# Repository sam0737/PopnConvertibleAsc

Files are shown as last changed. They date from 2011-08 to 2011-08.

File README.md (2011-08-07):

Pop'n Convertible ASC (Arcade Style Controller)
==============================================
中文版README請往下看。

[Pop'n Music][popnwiki] is a music simulation game produced by KONAMI.

This project is about making an arcade like, portable controller for the Pop'n Music game. The controller is designed to be connected to PC through USB. The buon push emulates keyboard key hits. (How to obtain the game to run on PC is out of topic)

Visit the [album][] to see some action shots.

Contents
--------
The files here are contains all of the design - hardware and software.

 * Mechanical Design
   A convertible stand design for holding the big buttons, designed to be made from acrylic (Plexiglas) and laser cut. This contains all the design source file and output.
 * Firmware
   Source code of the AVR Firmware to be loaded into any [LUFA][] supported device, to translate button pushes into keyboard keystrokes. It is a Keyboard HID and requires no driver for most OS.

Firmware Hardware
-----------------
The firmware is to translate button pushes as USB keyboard key press for PC. If you want to hook this up to Playstation, you don't need this firmware. You should deassemble a PS controller and hook it up instead.

The firmware can be compile for any [LUFA][] supported dev board, such as [minimus][]. Please refer to the LUFA website for supported models. Dev boards are usually sold at around 10 to 20 USD.

It is to be compiled with GCC + avr-libc. [WinAVR][] is such a toolchain for Windows. Upon connect, it requires no driver operate as it works as a keyboard device. 

Electronics
-----------
The buttons are to Port B pin 0 to pin 7, and Port C pin 7 from left to right.

 * On the microswitch: connect the Normal Open lead to the MCU, common lead to the GND.
 * On the button LED: connect positive lead to Vcc, negative lead to Normal Open of the microswitch. This assume the LED component has a built-in resistor inside (Those I bought does include a 300-ohm connected in series). The Vcc could be powered by 9V to 12V, as well as from the USB 5V directly except that it might not be bright enough.

Each button push would generate a key press signal of 1 to 9 accordingly.

Action shot
-----------
See [album]

Building Cost
-------------
Acrylic parts material + laser cutting: 30 USD
Minimus USB dev board: 10 USD
Buttons (LED + Microswitch included): 25 USD
Being able to play Pop'n Music with authentic controller: Priceless

Wires, soldering tools, etc. are not included.

Pop'n 可分拆式街機控制盤
========================
[Pop'n Music][popnwiki]是一套由KONAMI發行的音樂模擬遊戲。

這個專案是關於制作一個可與街機大小相比，但相對方便收納的控制器。控制器是以USB方式與電腦連接，按鍵會模擬成鍵盤按鈕一樣。(至於怎樣取得PC上運行的Pop'n Music版本則是題外話)

成品照片請看[相冊][album]。

內容
----
這裏提供了整件成品的所有文檔 - 硬件和軟件。

 * Mechanical Design - 硬件機械設計
   一個可分拆的腳架，當然是用來固定按鈕用的。設計上是以亞克力 (又名亞加力、有機玻璃)為材，以激光切割製成。這有了所有的設計原文件和輸出圖檔。
 * Firmware
   AVR固件的原代碼，適用於所有支持[LUFA][]架構的AVR開發版，用以將按鍵訊號轉成USB鍵盤訊號給電腦。電腦將會把它看成一般鍵盤硬件一樣，無需安裝任何驅動即可使用。

固件所用之硬件
--------------
這裏的固件是用來把按鍵訊號轉成USB鍵盤訊號給電腦。如果你要將這些按鈕接到Playstation的話，你不需要固件，也不需要AVR開發版，取而代之是你要肢解一個Playstation手掣並把線接上去。

本固件適用於所有支持[LUFA]的AVR硬件，例如[minimus]。有關硬件支持請參考LUFA的網頁。一般來說價格在於10到20美元之間。

本固件需要用GCC和avr-libc編譯才可使用。Windows用家可考慮使用[WivAVR][]來解決。硬件連上USB後，由於會模擬成鍵盤，所以電腦不需要配備任何驅動。

電子
----
那9個鍵由左至右應接到AVR B0到B7以及C7腳。

 * 微動開關方面: 常開(Normal Open - NO)接到AVR的腳。COM接地 (GND)。
 * LED方面:正極接Vcc，負極接到微動的常開腳。這假設你的LED模組中包含一個相應的電阻。(我買的有一個300歐電阻串連著) Vcc可以是其他9V-12V電源，USB的也行不過有點暗。

每按下按鈕就等同按了鍵盤的1-9一樣。

成品
----
看[圖][album]

製作成本
--------
亞克力材料及激光切割手工: 180人民幣
Minimus USB dev board: 60人民幣
特大按鈕，連微動和LED: 170人民幣
在家尤如在機舖中玩Pop'n: 此刻無賈

電線、焊接工具等不計算在內。

[popnwiki]: http://en.wikipedia.org/wiki/Pop'n_Music
[album]: https://picasaweb.google.com/103994691685219285374/PopnConvertibleAsc
[LUFA]: http://www.fourwalledcubicle.com/LUFA.php "Lightweight USB Framework for AVRs"
[minimus]: http://minimususb.com/
[WinAvr]: http://winavr.sourceforge.net/

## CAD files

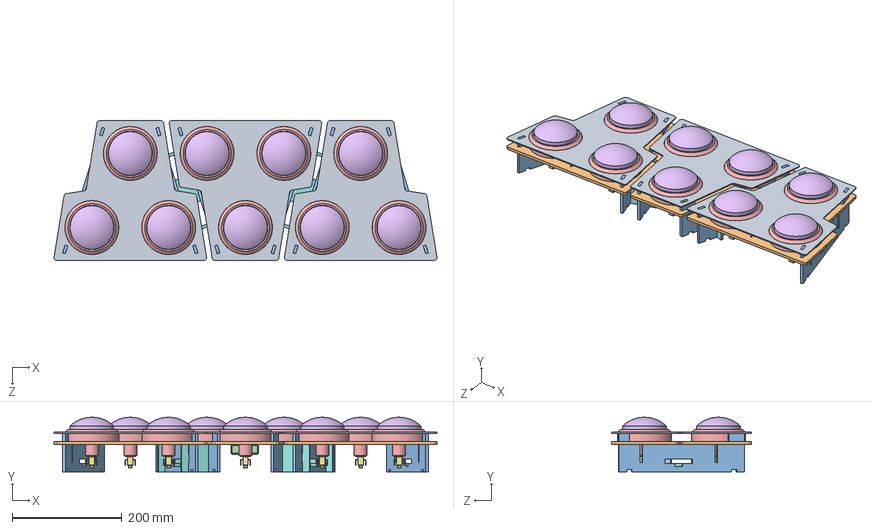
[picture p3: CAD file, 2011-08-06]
Mechnical Design/Assembly.SLDASM
698.2 x 99.6 x 255.0 mm
Top Plate x 3
Middle Plate x 3
Support x 6
Electronics
Button Shield x 9
Button Dome x 9
Microswitch x 9
Vertical Interlock x 6

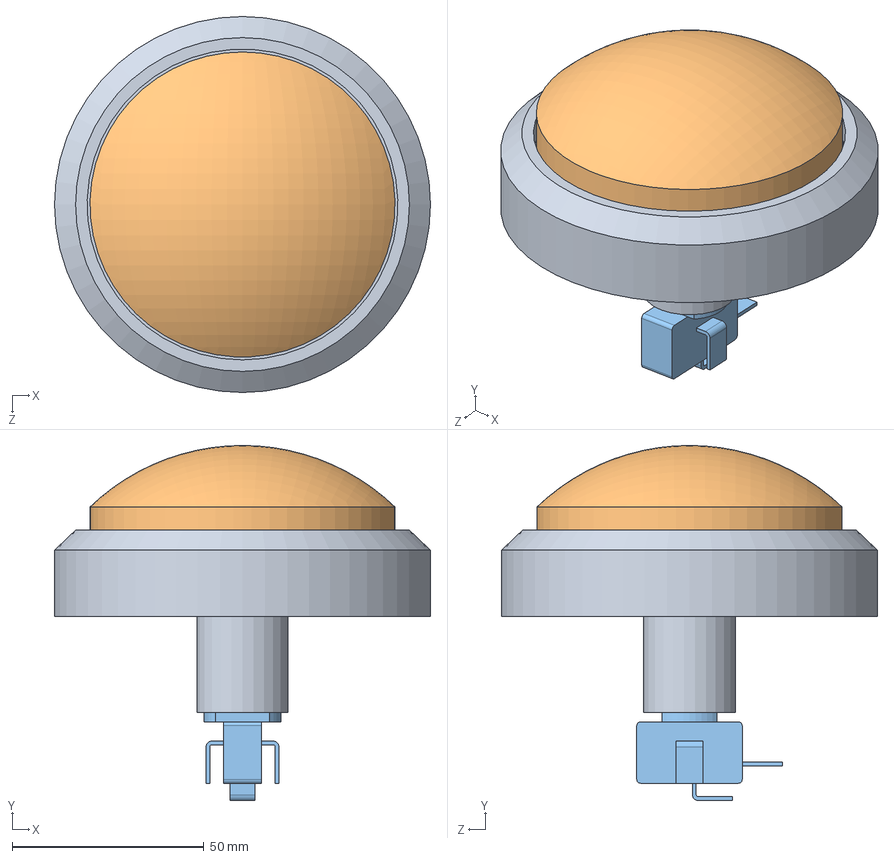
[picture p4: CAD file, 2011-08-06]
Mechnical Design/Button Assembly.SLDASM
98.0 x 92.6 x 98.0 mm
Button Shield
Button Dome
Microswitch

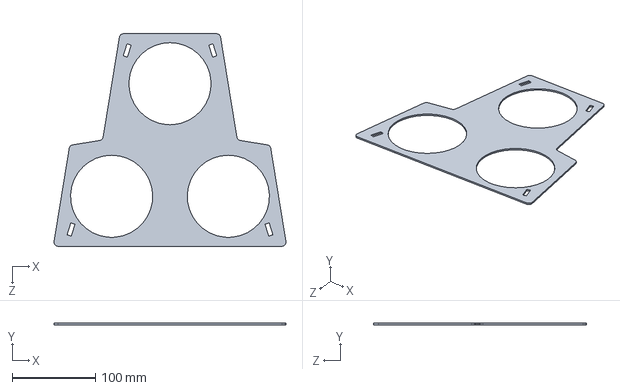
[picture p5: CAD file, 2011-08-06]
Mechnical Design/Top Plate.SLDPRT
278.2 x 2.00 x 255.0 mm

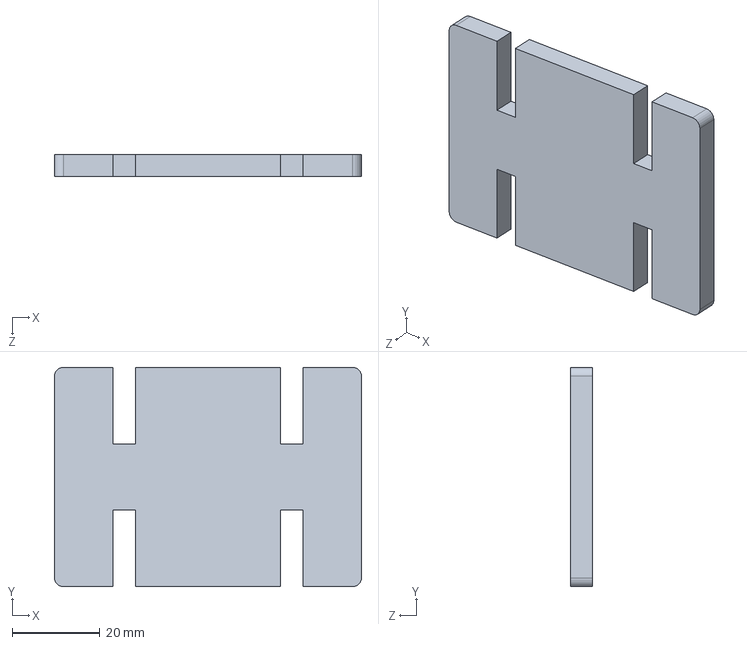
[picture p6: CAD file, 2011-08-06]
Mechnical Design/Vertical Interlock.SLDPRT
70.0 x 50.0 x 5.00 mm

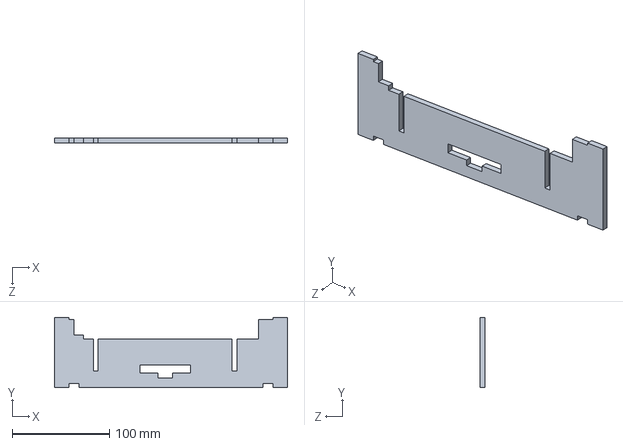
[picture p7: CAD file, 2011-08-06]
Mechnical Design/Support.SLDPRT
240.0 x 72.2 x 5.00 mm

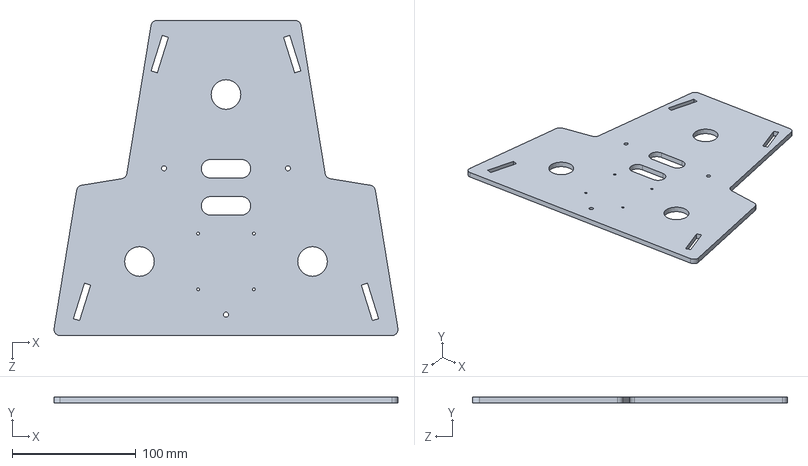
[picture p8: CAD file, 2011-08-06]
Mechnical Design/Middle Plate.SLDPRT
278.2 x 5.00 x 255.0 mm

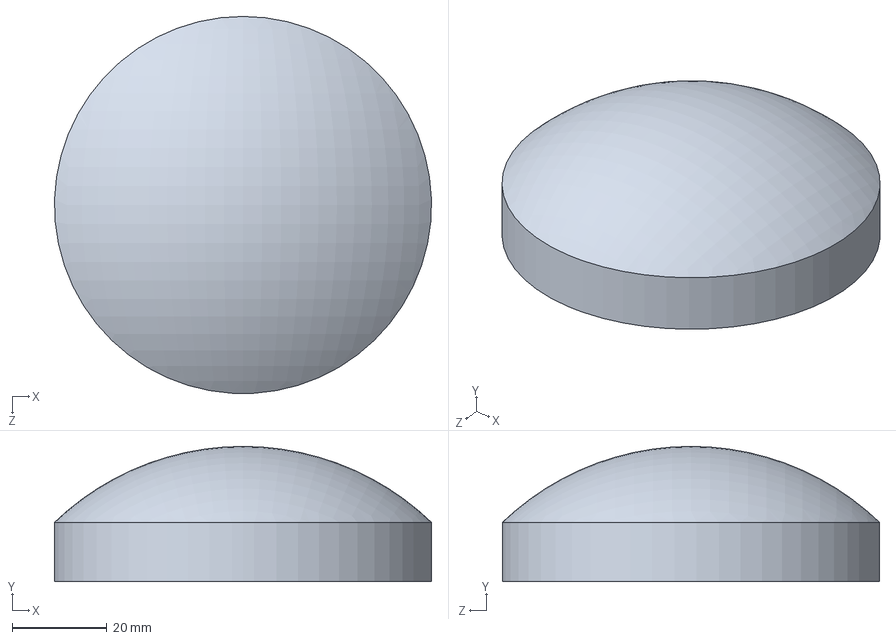
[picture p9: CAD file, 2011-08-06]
Mechnical Design/Button Dome.SLDPRT
79.5 x 28.5 x 79.5 mm

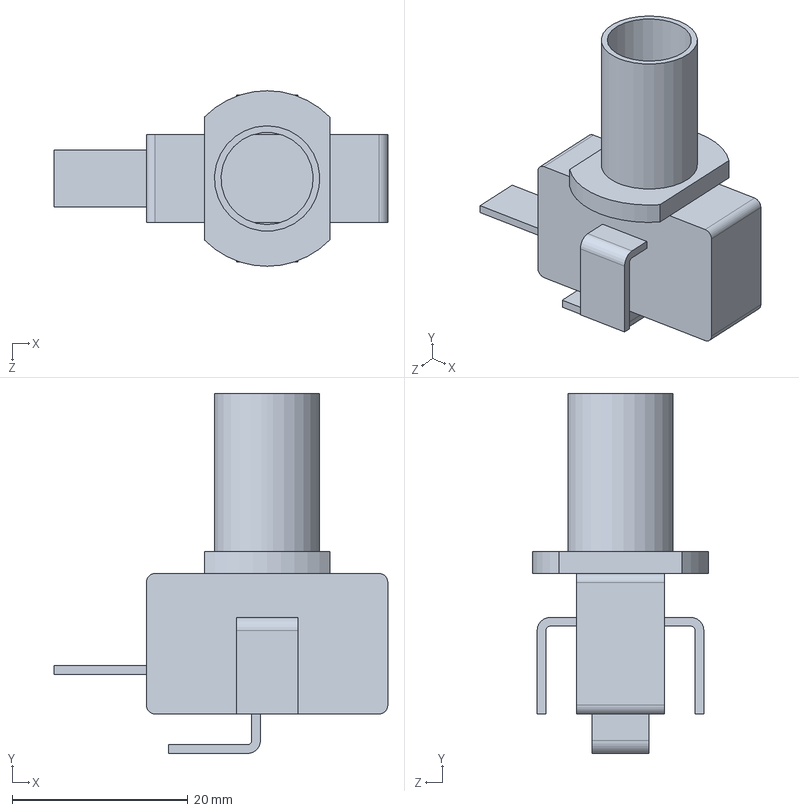
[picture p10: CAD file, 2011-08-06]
Mechnical Design/Microswitch.SLDPRT
38.0 x 41.0 x 20.0 mm

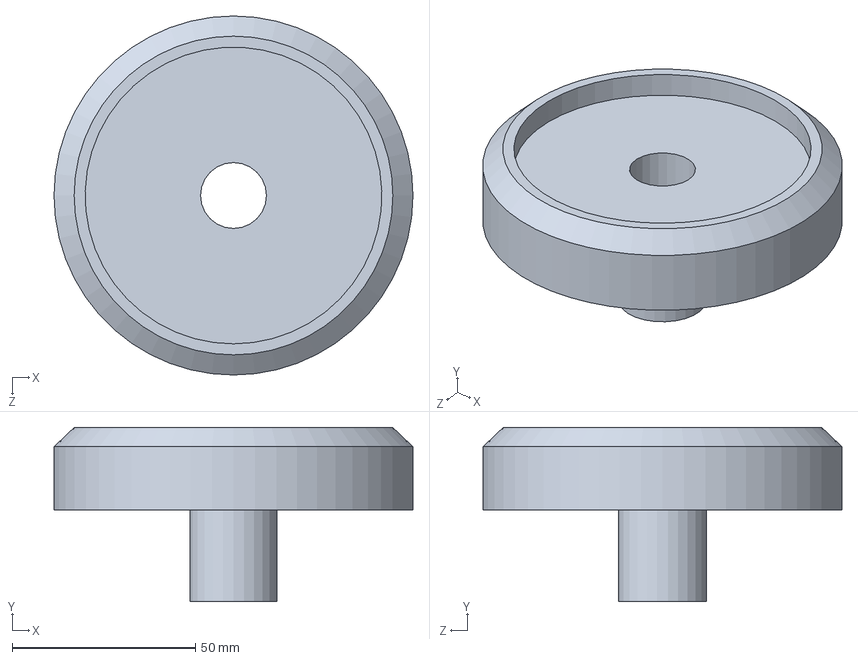
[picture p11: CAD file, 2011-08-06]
Mechnical Design/Button Shield.SLDPRT
98.0 x 47.5 x 98.0 mm

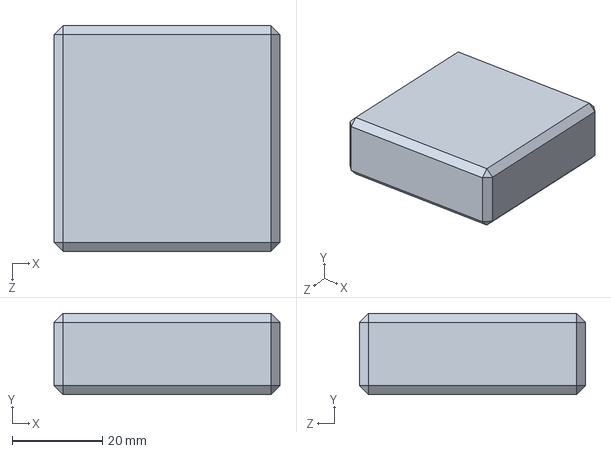
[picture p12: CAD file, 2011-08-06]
Mechnical Design/Electronics.SLDPRT
50.0 x 18.0 x 50.0 mm

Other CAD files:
Mechnical Design/03_Popn Asc.DXF
Mechnical Design/02_Popn Asc.DXF
Mechnical Design/01_Popn Asc.DXF
Mechnical Design/00_Popn Asc.DXF
Mechnical Design/Popn Asc.SLDDRW

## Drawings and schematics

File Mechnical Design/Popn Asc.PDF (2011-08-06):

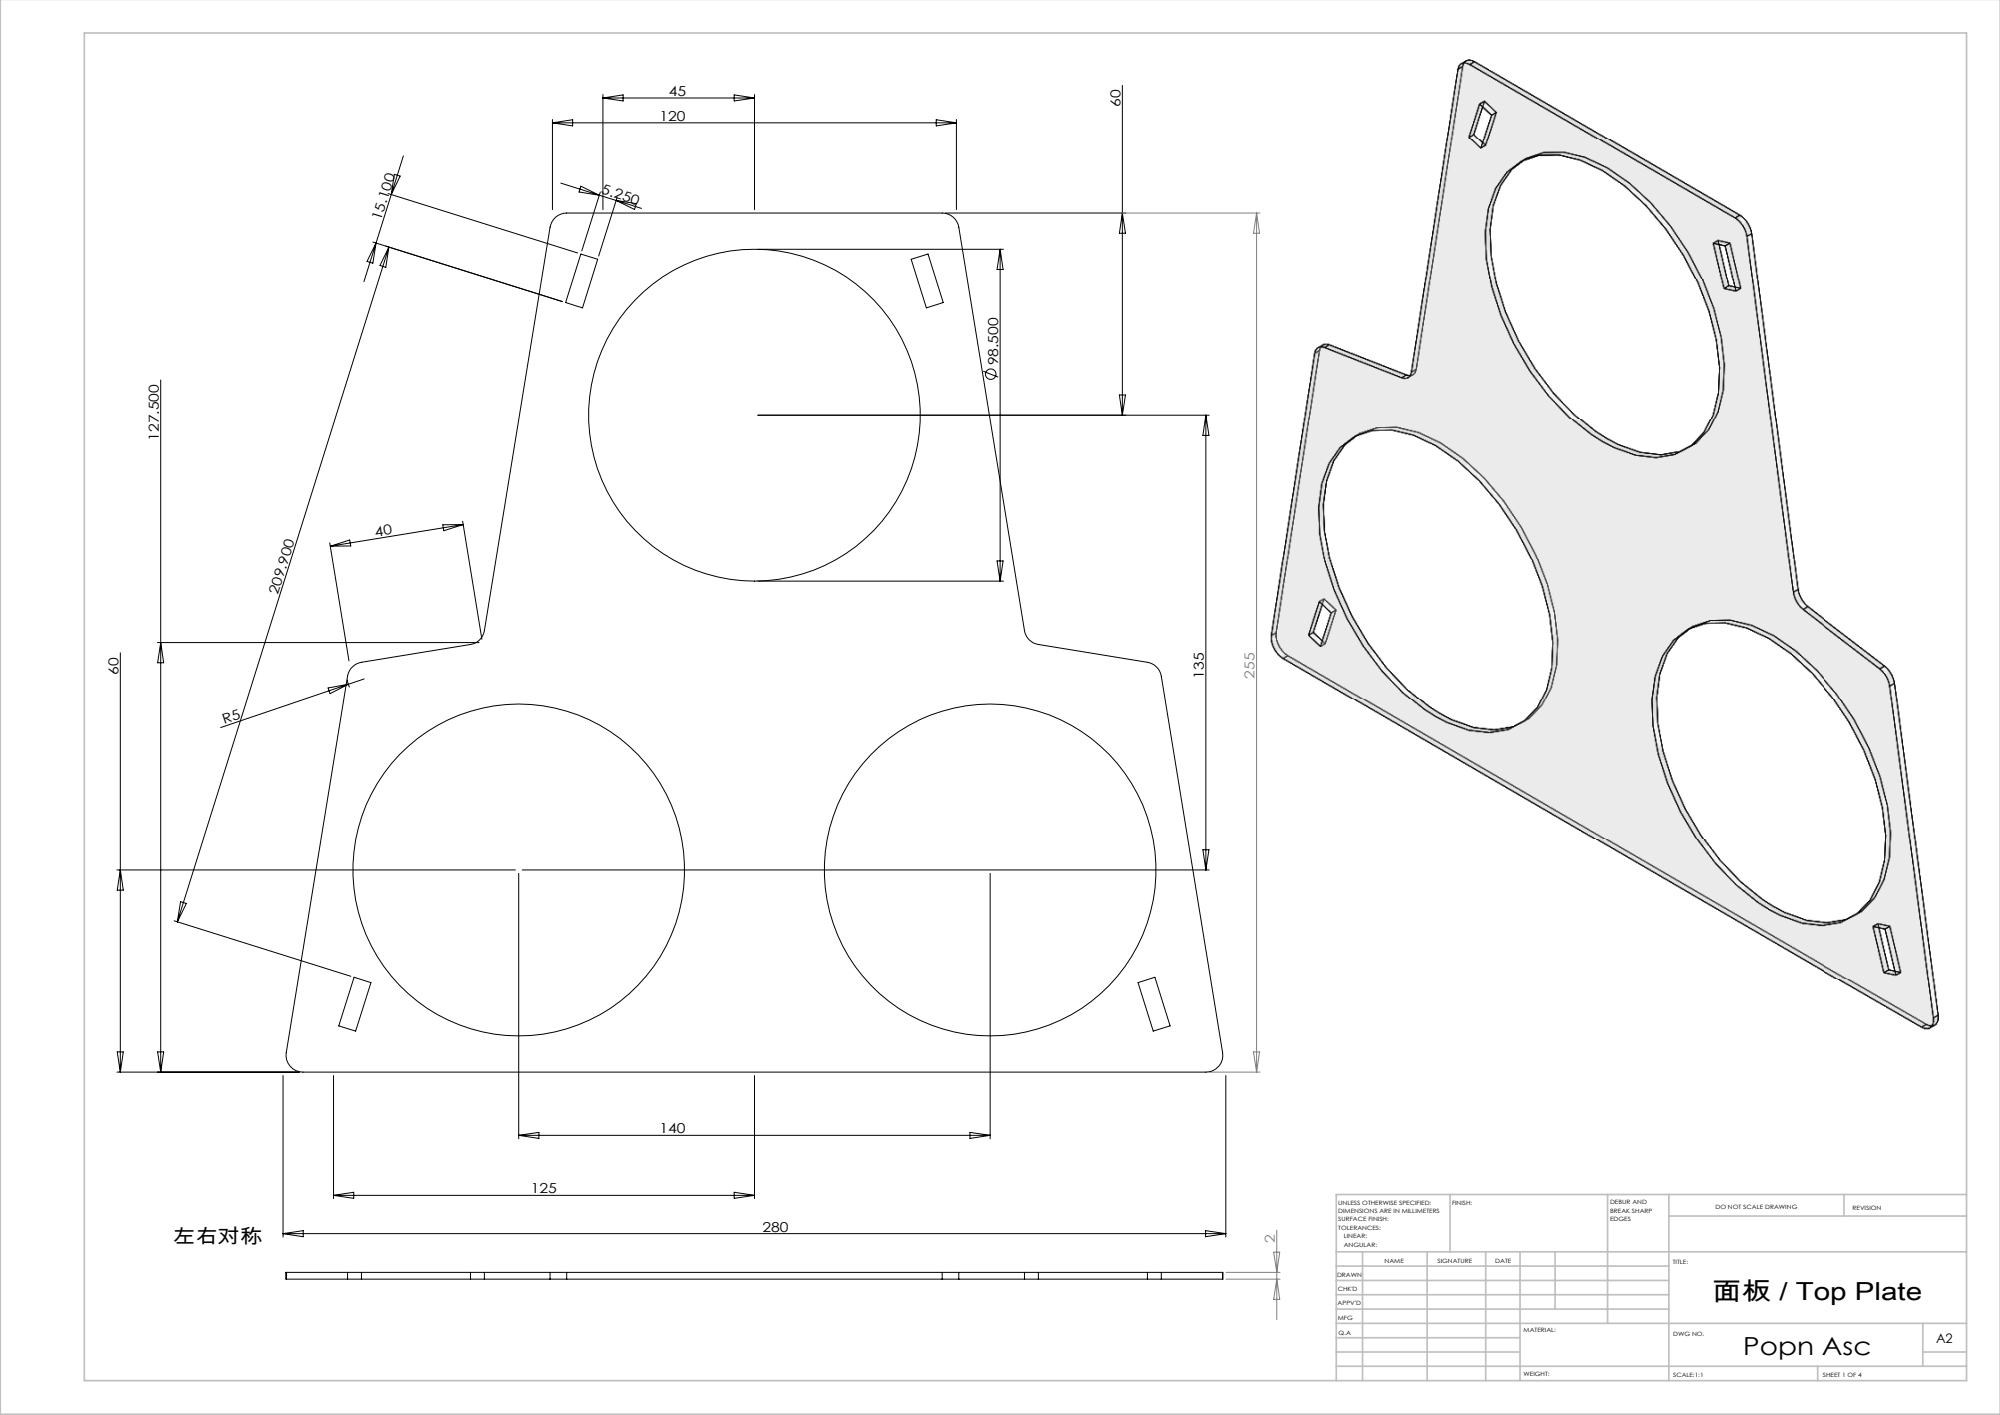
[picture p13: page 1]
SCALE:1:1; SHEET 1 OF 4; DO NOT SCALE DRAWING; REVISION; DEBUR AND BREAK SHARP; UNLESS OTHERWISE SPECIFIED:; FINISH:

DIMENSIONS ARE IN MILLIMETERS
SURFACE FINISH:
TOLERANCES:
LINEAR:
ANGULAR:

NAME | SIGNATURE | DATE | | | | TITLE: 面板 / Top Plate

DRAWN
CHK'D
APPV'D
MFG
Q.A | | | | MATERIAL: | DWG NO. Popn Asc WEIGHT: | A2

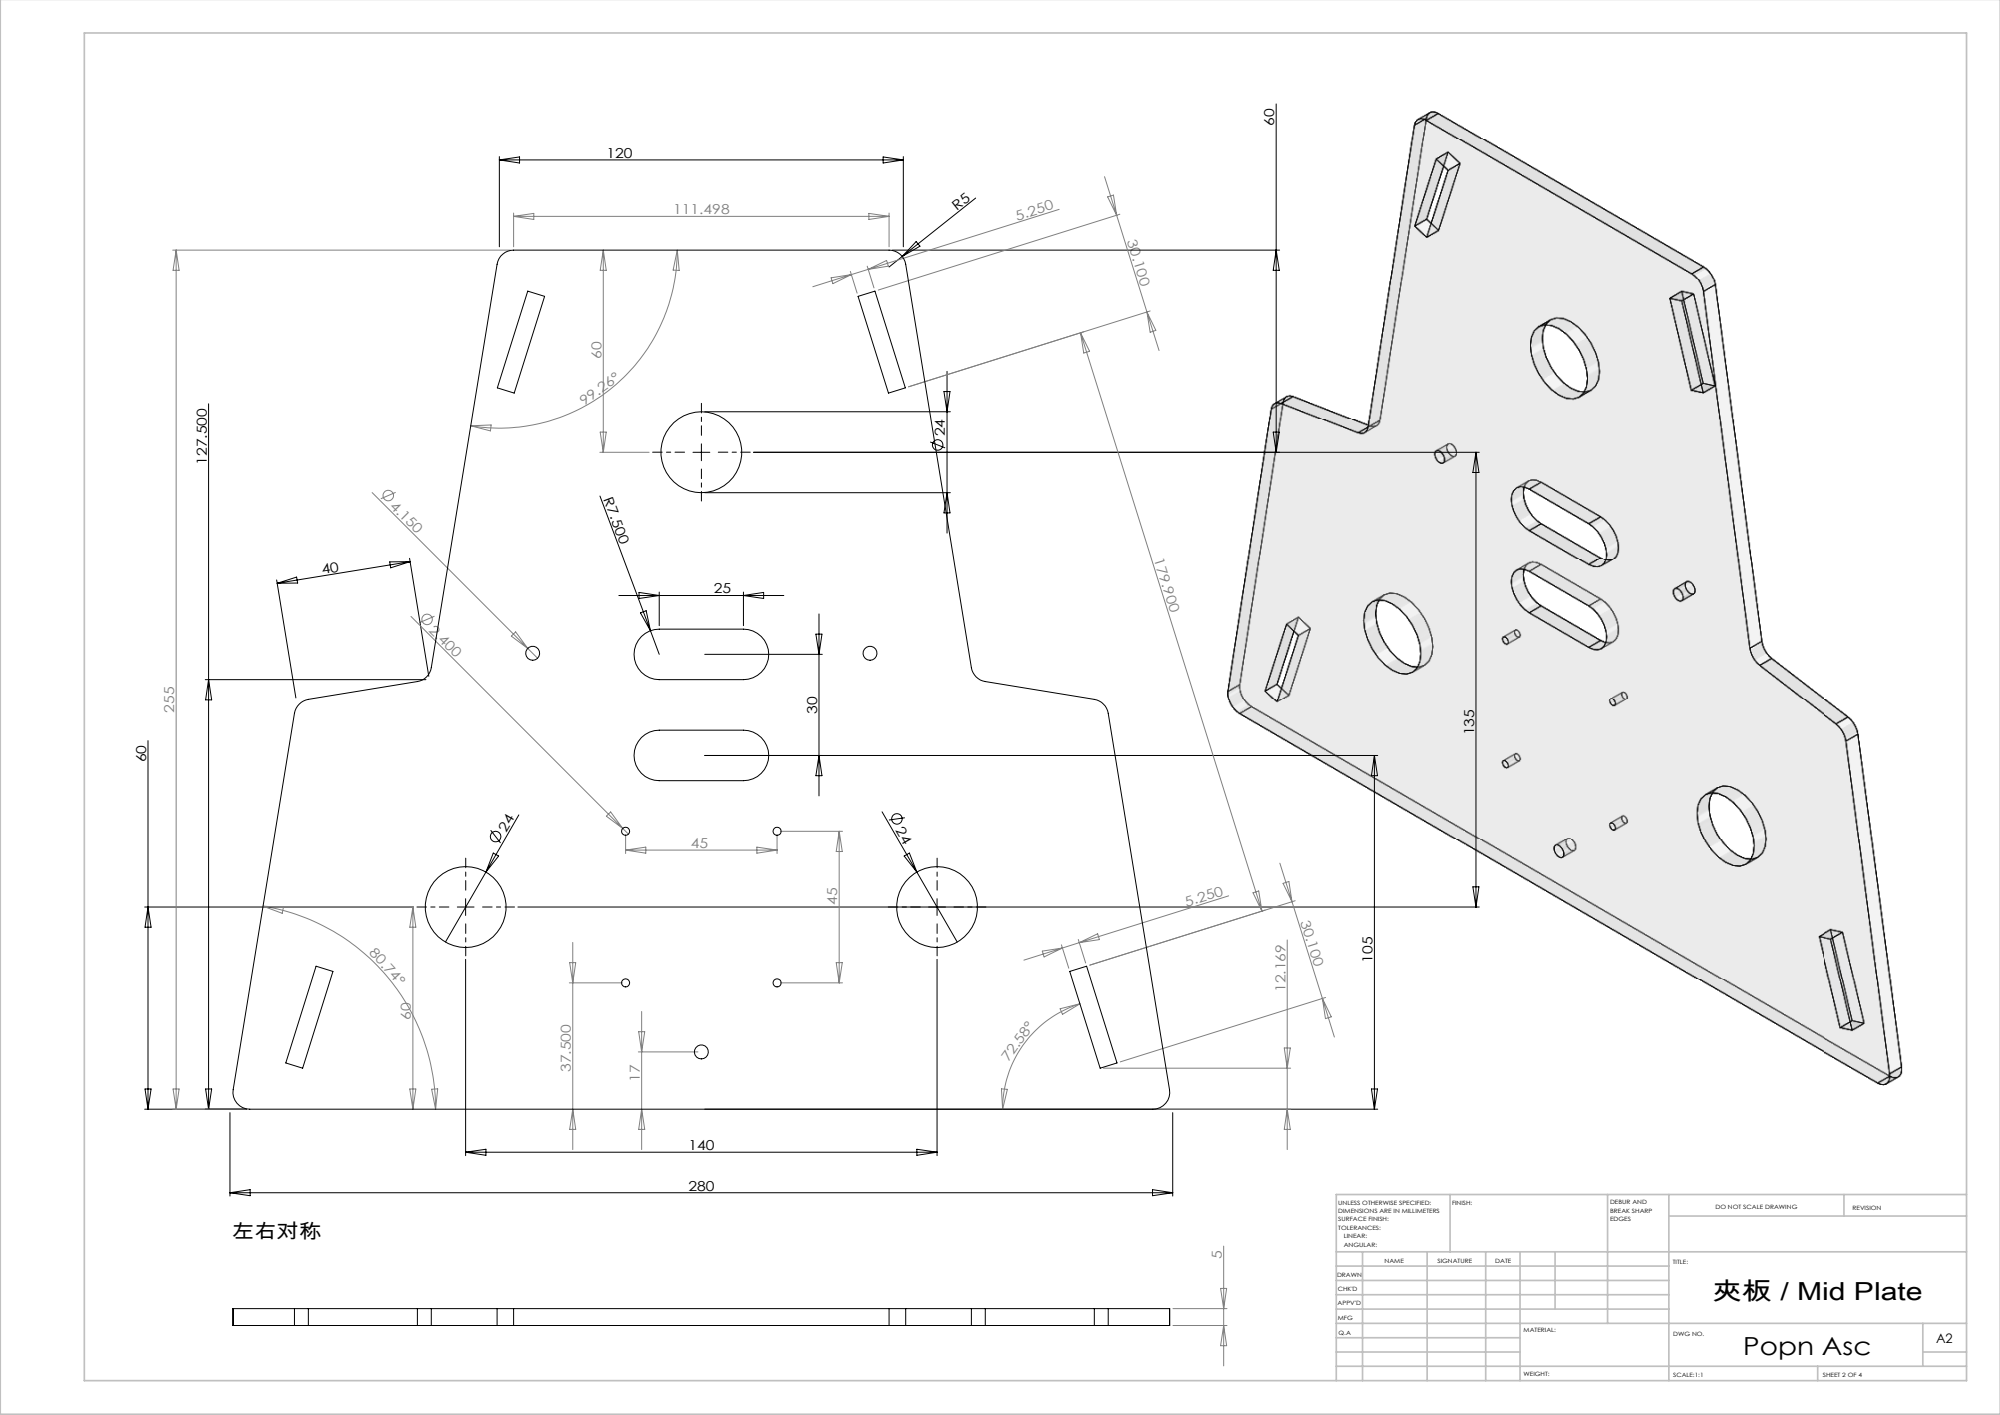
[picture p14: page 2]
DO NOT SCALE DRAWING; REVISION; DEBUR AND BREAK SHARP; UNLESS OTHERWISE SPECIFIED:; FINISH:

DIMENSIONS ARE IN MILLIMETERS
SURFACE FINISH:
TOLERANCES:
LINEAR:
ANGULAR:

NAME | SIGNATURE | DATE | TITLE: 夾板 / Mid Plate

DRAWN
CHK'D

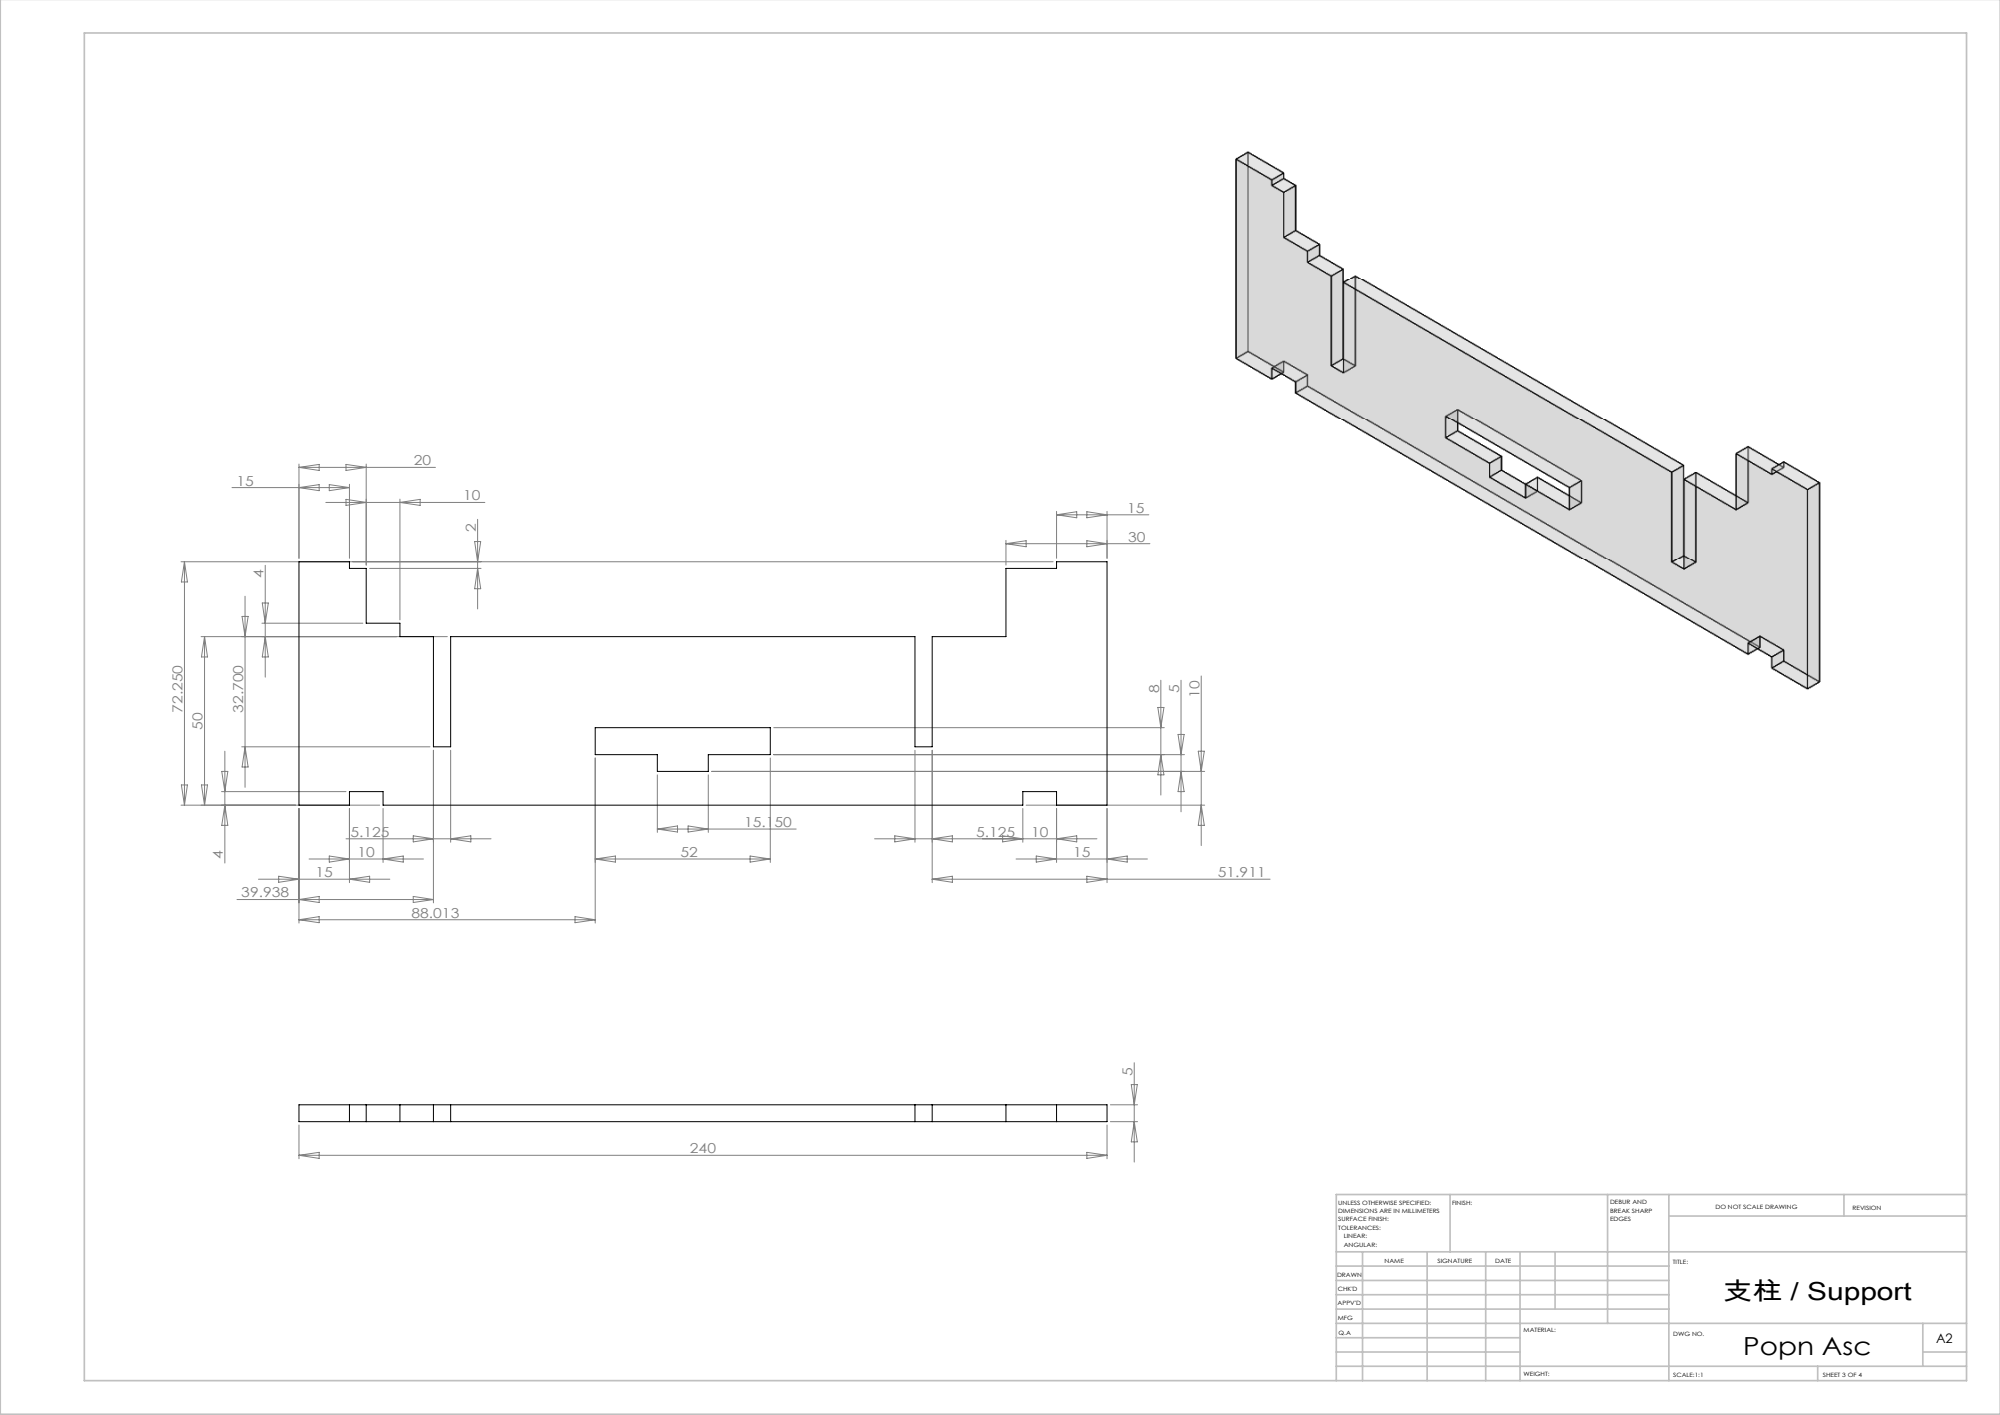
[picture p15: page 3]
DO NOT SCALE DRAWING; REVISION; DEBUR AND BREAK SHARP; UNLESS OTHERWISE SPECIFIED:; FINISH:

DIMENSIONS ARE IN MILLIMETERS
SURFACE FINISH:
TOLERANCES:
LINEAR:
ANGULAR:

NAME | SIGNATURE | DATE | TITLE: 支柱 / Support

DRAWN
CHK'D

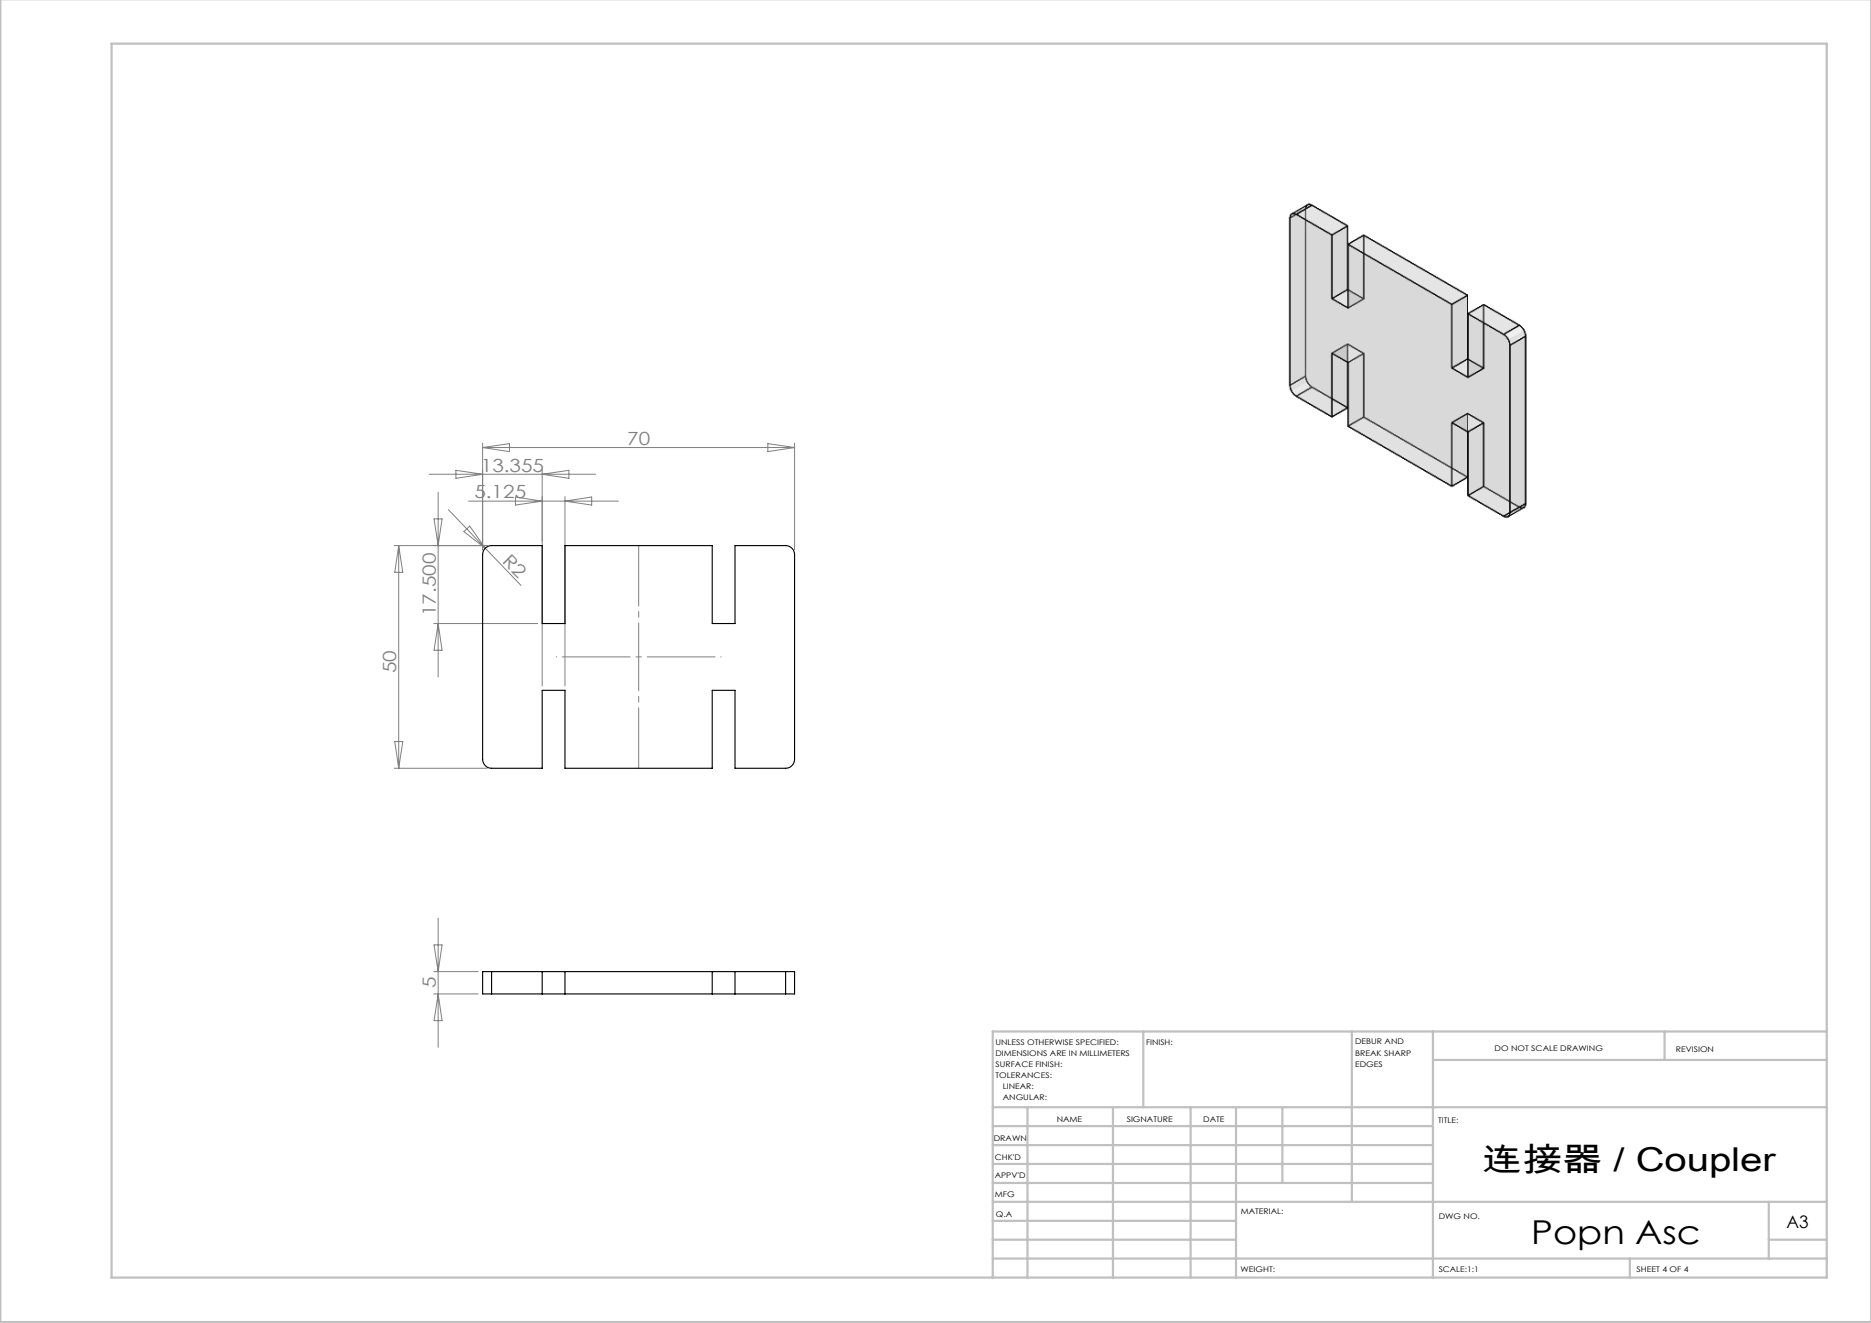
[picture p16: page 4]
DO NOT SCALE DRAWING; REVISION; DEBUR AND BREAK SHARP; UNLESS OTHERWISE SPECIFIED:; FINISH:

DIMENSIONS ARE IN MILLIMETERS
SURFACE FINISH:
TOLERANCES:
LINEAR:
ANGULAR:

NAME | SIGNATURE | DATE | TITLE: 连接器 / Coupler

DRAWN
CHK'D
APPV'D
MFG

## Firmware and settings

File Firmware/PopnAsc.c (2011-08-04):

/*
  Pop'n Convertible Arcade Style Controller Project
 
  Copyright 2011 Sam Wong (Sam /@/ hellosam /./ net)

  This work is licensed under the Creative Commons Attribution 3.0 
  Hong Kong License. 

  To view a copy of this license, visit 
  http://creativecommons.org/licenses/by/3.0/hk/ or send a letter to 
  Creative Commons, 444 Castro Street, Suite 900, 
  Mountain View, California, 94041, USA.

  --
  Code is based on the following LUFA Demo project
    [Demos\Device\ClassDriver\Keyboard]:

  Copyright 2011  Dean Camera (dean [at] fourwalledcubicle [dot] com)

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
*/

#include "PopnAsc.h"

#include <LUFA/Drivers/Board/LEDs.h>
#include <LUFA/Drivers/Board/Buttons.h>
#include <LUFA/Drivers/USB/USB.h>

#include <avr/io.h>
#include <avr/wdt.h>
#include <avr/power.h>
#include <avr/interrupt.h>
#include <stdbool.h>
#include <string.h>

/// Button edge changes are ignored for how many milliseconds?
#define DEBOUNCE_DOWN_TIME 20 
#define DEBOUNCE_UP_TIME 5

/// Current timestamp (millisecond)
unsigned char timeMark;

/// Button status management: When was the button pushed?
unsigned char lastTime[9];
/// Button status management: [Bitmap] The current button states (active high)
unsigned short buttonState;
/// Button status management: [Bitmap] If a button is in debounce delay phase, during which button state changes will be ignored
unsigned short buttonDebounce;

/** LUFA HID Class driver interface configuration and state information. */
USB_ClassInfo_HID_Device_t Keyboard_HID_Interface =
    {
        .Config =
            {
                .InterfaceNumber              = 0,

                .ReportINEndpointNumber       = DEVICE_ENDPOINT_NUM,
                .ReportINEndpointSize         = DEVICE_ENDPOINT_SIZE,
                .ReportINEndpointDoubleBank   = false,

                .PrevReportINBuffer           = NULL,
                .PrevReportINBufferSize       = DEVICE_ENDPOINT_SIZE,
            },
    };


void init_hardware(void);
void Popn_Buttons_Init(void);
void CalculateButtonState(void);

/** Main program entry point. This routine contains the overall program flow, including initial
 *  setup of all components and the main program loop.
 */
int main(void)
{
    init_hardware();

    sei();

    for (;;)
    {
        wdt_reset();
        HID_Device_USBTask(&Keyboard_HID_Interface);
        USB_USBTask();
    }
}

/** Configures the board hardware and chip peripherals for the demo's functionality. */
void init_hardware(void)
{
    // Turn on Watchdog
    wdt_enable(WDTO_500MS);

    // Disable clock prescaler
    clock_prescale_set(clock_div_1);

    // Initialize other driver
    LEDs_Init();
    Buttons_Init();
    Popn_Buttons_Init();
    USB_Init();
}

/** Initialize Pop'n buttons */
void Popn_Buttons_Init(void)
{
    // Buttons are connected to PB0 to PB7 and PC7
    DDRB  = 0;
    PORTB = 0xFF;
    
    DDRC  &= ~_BV(7);
    PORTC |=  _BV(7);
}

/** Event handler for the library USB Connection event. */
void EVENT_USB_Device_Connect(void)
{
    LEDs_TurnOffLEDs(LEDS_LED1);
}

/** Event handler for the library USB Disconnection event. */
void EVENT_USB_Device_Disconnect(void)
{
    LEDs_TurnOnLEDs(LEDS_LED1);
}

/** Event handler for the library USB Configuration Changed event. */
void EVENT_USB_Device_ConfigurationChanged(void)
{
    bool ConfigSuccess = true;

    ConfigSuccess &= HID_Device_ConfigureEndpoints(&Keyboard_HID_Interface);

    USB_Device_EnableSOFEvents();

    LEDs_TurnOnLEDs(LEDS_LED1);
}

/** Event handler for the library USB Control Request reception event. */
void EVENT_USB_Device_ControlRequest(void)
{
    HID_Device_ProcessControlRequest(&Keyboard_HID_Interface);
}

/** Event handler for the USB device Start Of Frame event. */
void EVENT_USB_Device_StartOfFrame(void)
{
    HID_Device_MillisecondElapsed(&Keyboard_HID_Interface);
    CalculateButtonState();
}

void EVENT_USB_Device_Suspend()
{
    wdt_disable();
}

void EVENT_USB_Device_WakeUp()
{
    wdt_enable(WDTO_500MS);
}

void CalculateButtonState(void)
{
    unsigned char i;    
    unsigned short currentState;
    unsigned short oldState = buttonState;
    short change;
    
    timeMark++;
    
    // If any debug button is presed
    if (Buttons_GetStatus() != 0) 
    {
        // Assume all key down
        currentState = (unsigned short) 0x01FF;
    } else {
        // Read actual push button 
        // (Push button are active low, so remember to flip them)
        currentState = (unsigned short) ~(((PINC & _BV(7)) << 1) | PINB);
    }
    
    // Use old state if still in debounce interval, or else new state
    buttonState = (buttonState & buttonDebounce) | (~buttonDebounce & currentState);

    // Was the state changed?
    change = buttonState ^ oldState;
    
    for (i = 0; i < 9; i++)
    {
        if (buttonDebounce & _BV(i))
        {
            // Release debounce state if interval has passed
            if (timeMark == lastTime[i])
            {
                buttonDebounce &= ~_BV(i);
            }
        } else {
            // If change, kick into debounce state
            if (change & _BV(i)) {
                lastTime[i] = timeMark + (buttonState & _BV(i) ? DEBOUNCE_DOWN_TIME : DEBOUNCE_UP_TIME);
                buttonDebounce |= _BV(i);
            }
        }
    }
}

/** HID IN report */
bool CALLBACK_HID_Device_CreateHIDReport(USB_ClassInfo_HID_Device_t* const HIDInterfaceInfo, uint8_t* const ReportID,
                                         const uint8_t ReportType, void* ReportData, uint16_t* const ReportSize)
{
    uint8_t* data = (uint8_t*) ReportData;

    data[0] = buttonState & 0xFF;
    data[1] = (buttonState >> 8) & 0xFF;

    *ReportSize = 2;

    return true;
}

/** HID OUT report */
void CALLBACK_HID_Device_ProcessHIDReport(USB_ClassInfo_HID_Device_t* const HIDInterfaceInfo,
                                          const uint8_t ReportID,
                                          const uint8_t ReportType,
                                          const void* ReportData,
                                          const uint16_t ReportSize)
{
    // No-op
}

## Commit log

2011-07-31 Version 1 - Working Key - USB - First mechanical design
    [00_Popn Asc.DXF, 01_Popn Asc.DXF, 02_Popn Asc.DXF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]
2011-08-02 Assembly: - Fix: The supports collide with the buttons. - Make the corner rounds - Add PCB holder
    [Assembly.SLDASM, Electronics.SLDPRT, Interlock.SLDPRT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]
2011-08-02 Firmware rewritten under LUFA framework Updated mechanical drawing, license and readme.
    [00_Popn Asc.DXF, 01_Popn Asc.DXF, 02_Popn Asc.DXF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]
2011-08-04 Debounce logic was busted. Now fixed. Tab to spaces
    [PopnAsc.c]
2011-08-05 Adding button assembly
    [Assembly.SLDASM, Button Assembly.SLDASM, Button Dome.SLDPRT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]
2011-08-06 New interlocking for more stable connection
    [Assembly.SLDASM, Button Assembly.SLDASM, Button Dome.SLDPRT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]
2011-08-06 Updated drawing and Readme
    [00_Popn Asc.DXF, 01_Popn Asc.DXF, 02_Popn Asc.DXF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]
